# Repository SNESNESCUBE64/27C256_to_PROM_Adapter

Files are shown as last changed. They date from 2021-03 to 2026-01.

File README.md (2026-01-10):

# 27C256 to PROM Adapter

The purpose of this repo is to replace the old obselete PROMs. It is recommended that you use the Atmel AT27C256-45PU. It is a very fast OTP EPROM that can be purchased from reputable sellers such as mouser.com. All board designs are done in Kicad.

*Just as a disclaimer, these are not garunteed to work with everything. Not all of the adapters have been verified to work. As these are verified working, the table will be updated.*

## Chip Verification
| Chip | Boards Made? | Verified Working? | Test Details |
|---|---|---|---|
| 82S123 | No | No | Untested |
| 82S126 | Yes | No | Untested |
| 82S129 | Yes | Yes | Tested audio PROM 1D and Color PROM 1C on Galaga, ran for 4 hours with no issues  |
| 82S130 | Yes | No | Untested |
| 82S131 | Yes | No | Untested |
| 82S135 | No | No | Untested |
| 82S137 | No | No | Untested |
| 82S141 | No | No | Untested |
| 82S141 | No | No | Untested |
| 82S147 | No | No | Untested |
|TKG Elim| Yes | Yes | Tested working on a TRS2 Radarscope PCB set. Ran with no issues. |

## 82S123
Just a drop in replacement, no jumpers or anything. Just solder the pins, burn the rom, then solder the rom and insert in the socket!

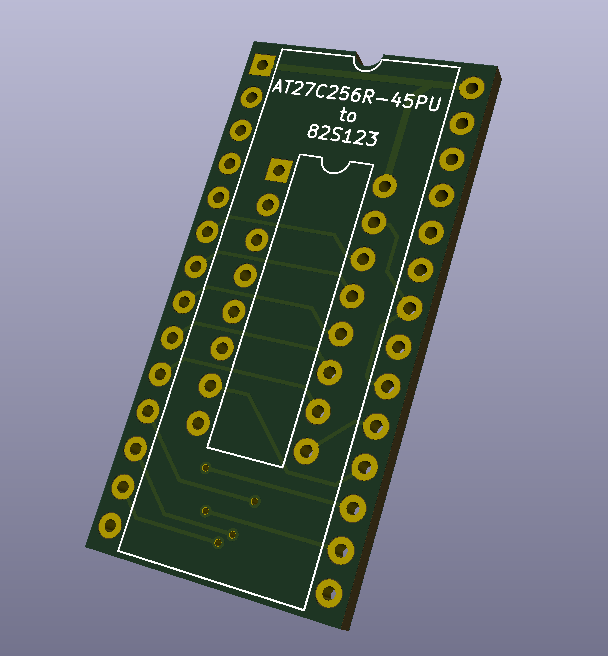
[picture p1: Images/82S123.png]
82S123


## 82S126/82S129/82S130/82S131
There are two jumpers, for 82S130/82S131, jump pins 1 and 2 for both jumper sets. For 82S126/82S129, jump pins 2 and 3 for both jumper sets. One thing to note with this, only the 4 low bits are used with this one. Make sure your binaries are not using the data in the upper bits.

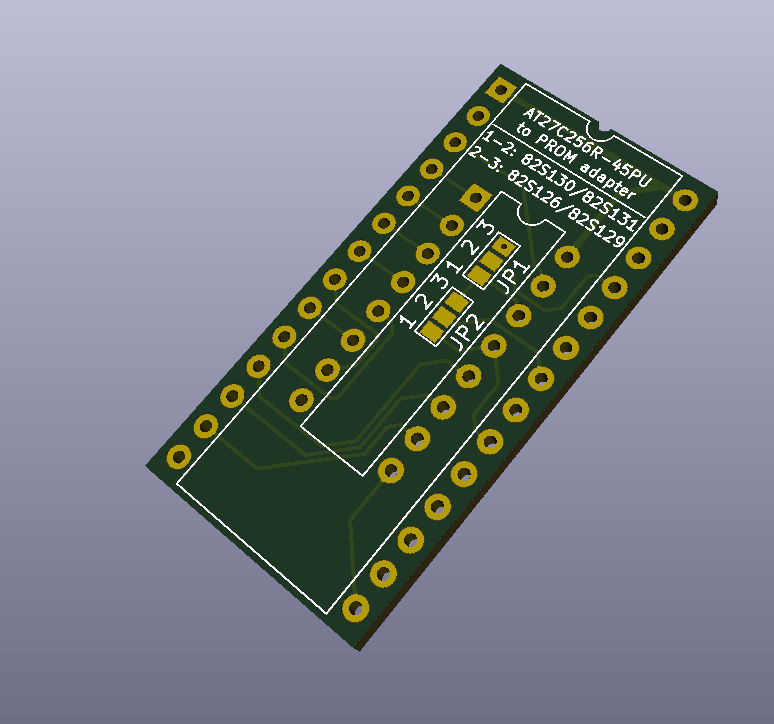
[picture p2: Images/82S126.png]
82S126/82S129/82S130/82S131


## 82S135
Just a drop in replacement, no jumpers or anything. Just solder the pins, burn the rom, then solder the rom and insert in the socket! Uses the upper 256 bytes.

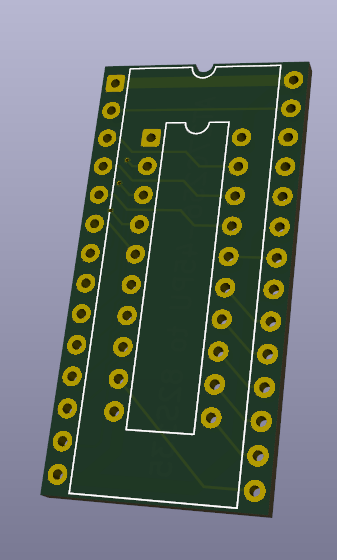
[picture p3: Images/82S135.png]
82S135


## 82S137
Just a drop in replacement, no jumpers or anything. Just solder the pins, burn the rom, then solder the rom and insert in the socket! One thing to note with this, only the 4 low bits are used with this one. Make sure your binaries are not using the data in the upper bits.

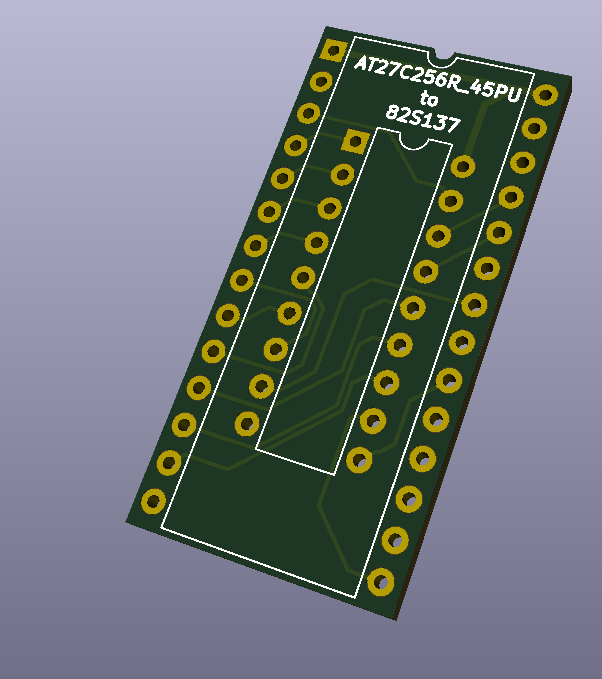
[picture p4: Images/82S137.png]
82S137


## 82S141
This one is a little bit different, it uses active circuitry to combine the chip select. It basically adds a 74ALS02 and a 0.1uF 0603 sized capacitor. The reason is because the 82S141 has four chip enables where as the 27C256 only has two. 

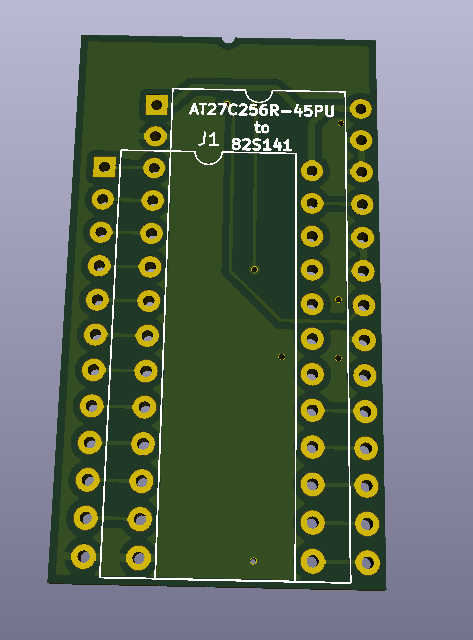
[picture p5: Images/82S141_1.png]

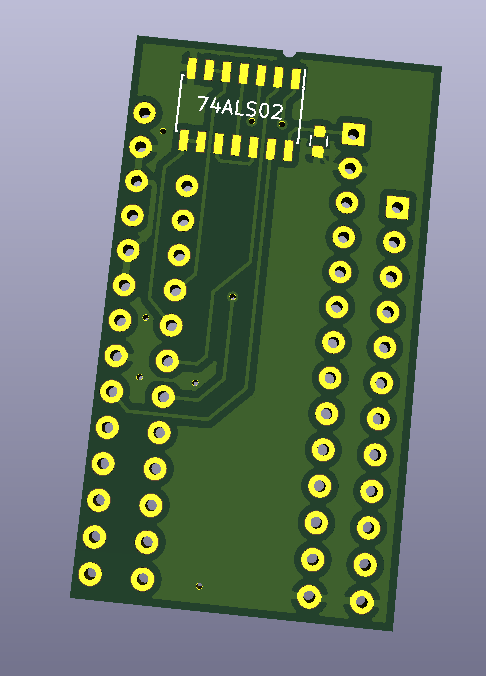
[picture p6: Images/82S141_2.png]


## TKG CPU PROM Eliminator
This is a board that combines the two PROMs found on the CPU board of Donkey Kong and Radarscope PCBs. It is more of an application than a direct PROM adapter. View the readme in the TKG CPU Eliminator folder for more details.

This has been tested and verified working on a TRS2 Radarscope PCB, but should be compatible with the following game boards:
- Radarscope (TRS2)
- Donkey Kong (TKG2)
- Donkey Kong (TKG3)
- Donkey Kong (TKG4)

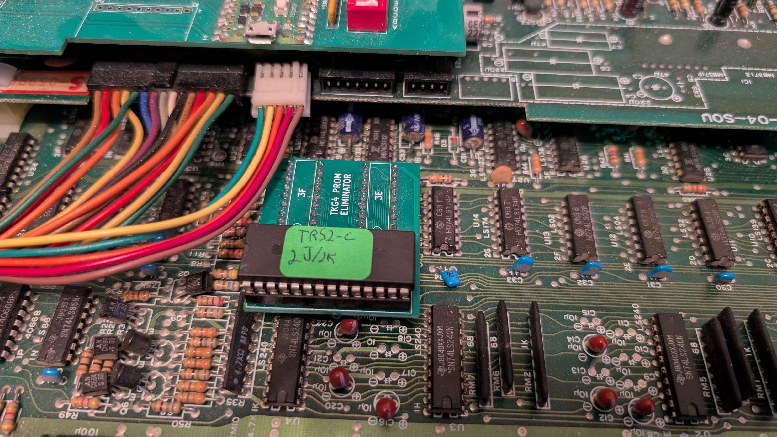
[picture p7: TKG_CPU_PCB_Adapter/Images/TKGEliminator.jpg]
TKG PROM Eliminator


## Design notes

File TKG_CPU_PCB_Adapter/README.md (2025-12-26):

# TKG PROM Eliminator
This board was designed as an alternative to the bipolar PROMs commonly found on Radarscope and Donkey Kong CPU PCBs. This combines both PROMs into one single IC to save on chips in the event that the PROMs are missing or defective. Note, this is intended to be used with **AT27C256R-45PU** high speed EPROMs. These are still available as of this time, so it makes a suitable alternative. It fits into the original two sockets without any board modifications. 

Assembled Unit

## Combining the PROM Files
Because this board relies on combining both of these PROMs into one (both are 4 bit), one has to be the upper bits and the other has to be the lower bits. 2J/3E is the lower bits, 2K/3F is the upper bits. A python script has been provided to combine the files.

Use of the python script is not required. However, I wrote it so that manual shifting of the bits and merging is unecessary. The upper PROM files have to have their byte contents shifted left by 4 and then merged together. This can be done manually but is quite tedious and prone to error. The example down shows a partial merge of the first 32 bytes.

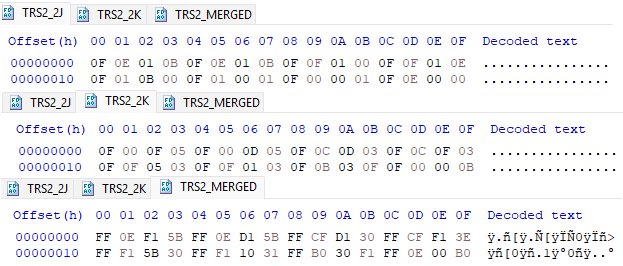
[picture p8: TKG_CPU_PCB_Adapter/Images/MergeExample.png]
Merge Exmaple


### Using the python script
The only pre-requisite is that you have to have a newer version of Python 3 installed on your computer. In order to use the python script, you will have to define the file names that you want to use in the header of the python script. You will also have to copy your PROM files into the "Scripts" folder in order to merge them.

```python
#user defined file names
promLowFilename = "TRS2_2J"
promHighFilename = "TRS2_2K"
promMergedFilename = "TRS2_MERGED"
```

promLowFilename is the file name of the 2J or 3E PROM, this is the lower bits. promHighFilename is the file name of the 2K/3F PROM, this is the upper bits. promMergedFilename is output file name.

A simple bat file is provided to easily execute it, it assumes that you have "python" as an environment variable. If you do not have that, then you will need to execute the python script another way.

### Burning the EPROM
You do not have to do anything special to burnt he eprom once you have the merged file. Duplicating to fill the EPROM is unecessary. Just load the merged PROM files at the beginning of memory for your programmer perform the programming.

## Compatibility
This has been tested and verified working on a TRS2 Radarscope PCB, but should be compatible with the following game boards:
- Radarscope (TRS2)
- Donkey Kong (TKG2)
- Donkey Kong (TKG3)
- Donkey Kong (TKG4)

It might also be compatible with Donkey Kong JR CPU PCB Boards, but I have not verified the spacing.

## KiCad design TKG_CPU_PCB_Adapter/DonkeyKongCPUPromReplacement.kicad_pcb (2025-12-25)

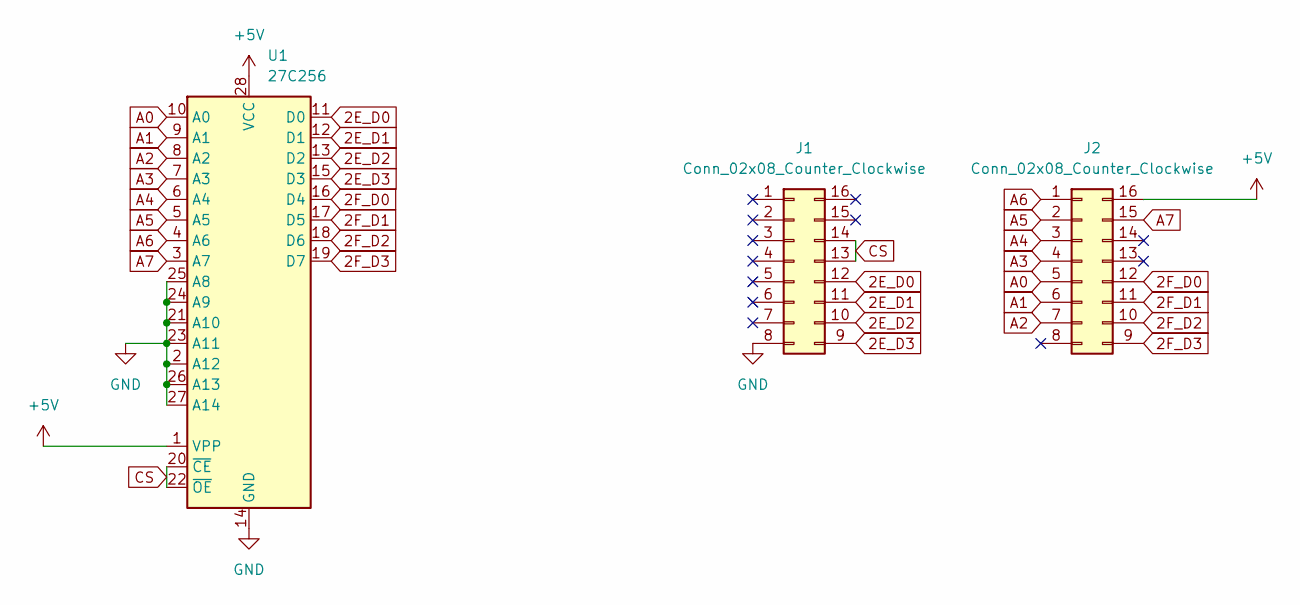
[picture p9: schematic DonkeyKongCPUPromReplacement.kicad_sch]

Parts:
J1, J2: Conn_02x08_Counter_Clockwise; DIP-16_W7.62mm
U1: 27C256; DIP-28_W15.24mm_Socket

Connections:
2E_D0: J1.12, U1.11 (D0)
2E_D1: J1.11, U1.12 (D1)
2E_D2: J1.10, U1.13 (D2)
2E_D3: J1.9, U1.15 (D3)
2F_D0: J2.12, U1.16 (D4)
2F_D1: J2.11, U1.17 (D5)
2F_D2: J2.10, U1.18 (D6)
2F_D3: J2.9, U1.19 (D7)
+5V: J2.16, U1.1 (VPP), U1.28 (VCC)
A0: J2.5, U1.10 (A0)
A1: J2.6, U1.9 (A1)
A2: J2.7, U1.8 (A2)
A3: J2.4, U1.7 (A3)
A4: J2.3, U1.6 (A4)
A5: J2.2, U1.5 (A5)
A6: J2.1, U1.4 (A6)
A7: J2.15, U1.3 (A7)
CS: J1.13, J1.14, U1.20 (~CE), U1.22 (~OE)
GND: J1.8, U1.2 (A12), U1.14 (GND), U1.21 (A10), U1.23 (A11), U1.24 (A9), U1.25 (A8), U1.26 (A13), U1.27 (A14)

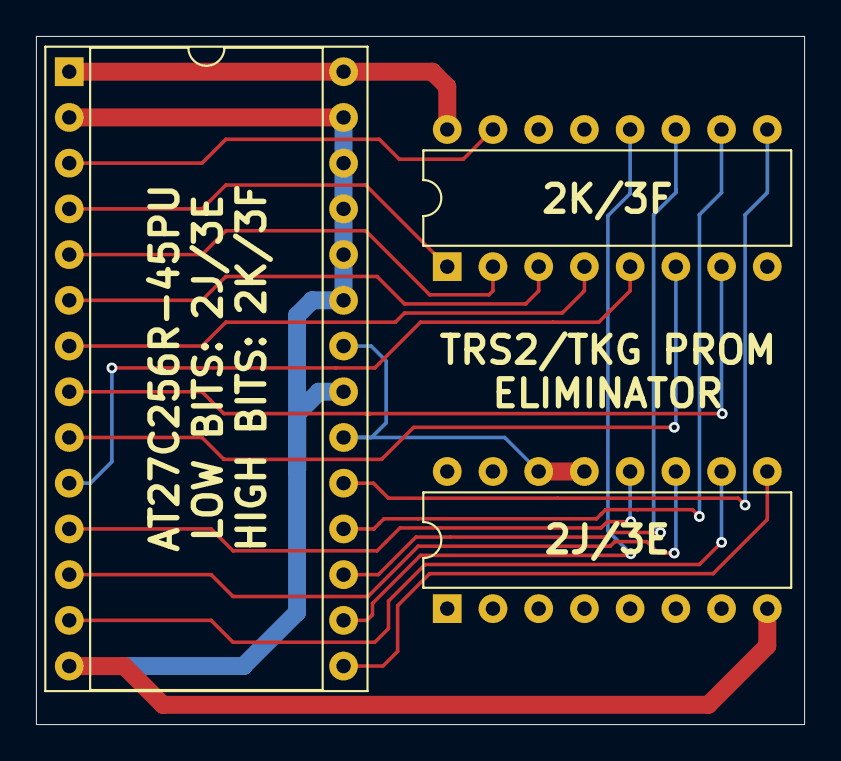
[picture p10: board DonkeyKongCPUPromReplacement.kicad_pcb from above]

Board: 2 copper layers, 42.7 x 38.2 mm, 3 parts (0 on the bottom side), 19 nets.

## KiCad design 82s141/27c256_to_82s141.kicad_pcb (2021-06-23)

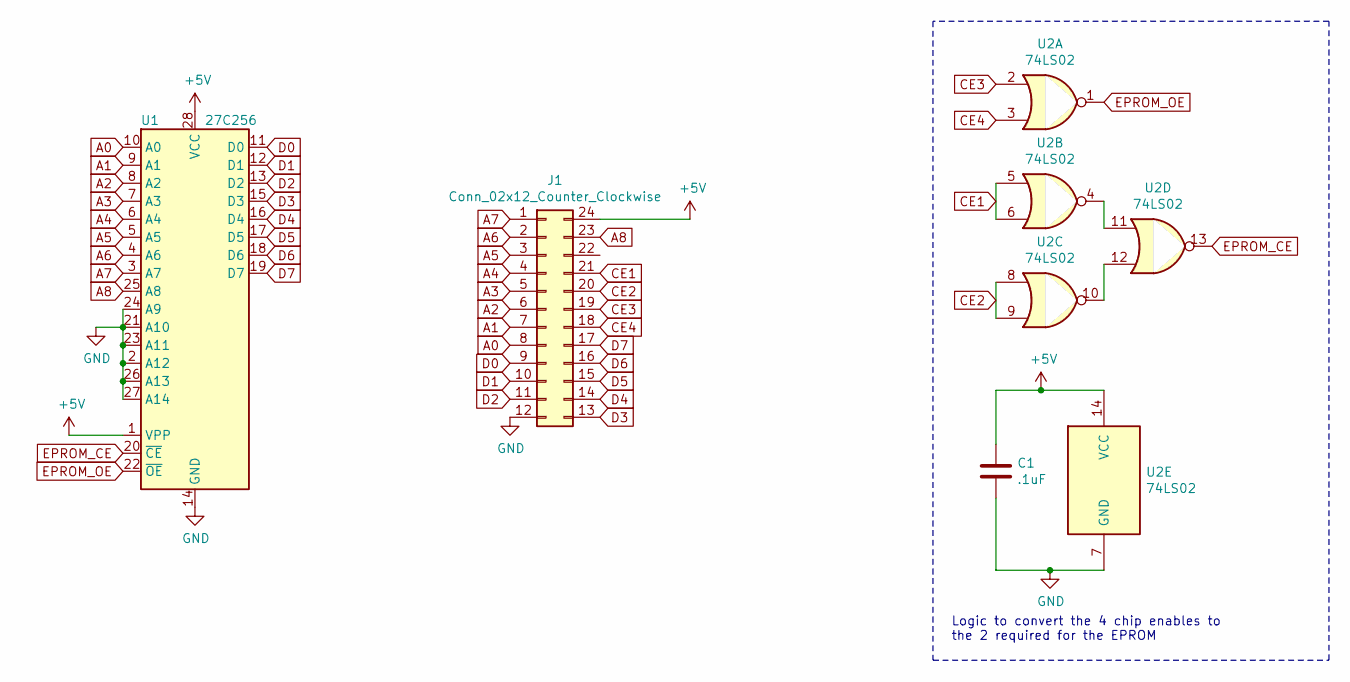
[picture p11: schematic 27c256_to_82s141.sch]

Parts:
C1: .1uF; C_0603
J1: Conn_02x12_Counter_Clockwise; DIP-24_W7.62mm
U1: 27C256; DIP-28_W15.24mm
U2: 74LS02; SOIC-14_3.9x8.7mm_Pitch1.27mm

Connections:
+5V: C1.1, J1.24, U1.1 (VPP), U1.28 (VCC), U2.14 (VCC)
A0: J1.8, U1.10 (A0)
A1: J1.7, U1.9 (A1)
A2: J1.6, U1.8 (A2)
A3: J1.5, U1.7 (A3)
A4: J1.4, U1.6 (A4)
A5: J1.3, U1.5 (A5)
A6: J1.2, U1.4 (A6)
A7: J1.1, U1.3 (A7)
A8: J1.23, U1.25 (A8)
CE1: J1.21, U2.5, U2.6
CE2: J1.20, U2.8, U2.9
CE3: J1.19, U2.2
CE4: J1.18, U2.3
D0: J1.9, U1.11 (D0)
D1: J1.10, U1.12 (D1)
D2: J1.11, U1.13 (D2)
D3: J1.13, U1.15 (D3)
D4: J1.14, U1.16 (D4)
D5: J1.15, U1.17 (D5)
D6: J1.16, U1.18 (D6)
D7: J1.17, U1.19 (D7)
EPROM_CE: U1.20 (~CE), U2.13
EPROM_OE: U1.22 (~OE), U2.1
GND: C1.2, J1.12, U1.2 (A12), U1.14 (GND), U1.21 (A10), U1.23 (A11), U1.24 (A9), U1.26 (A13), U1.27 (A14), U2.7 (GND)
unnamed: U2.10, U2.12
unnamed: U2.4, U2.11

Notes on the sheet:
Logic to convert the 4 chip enables to the 2 required for the EPROM

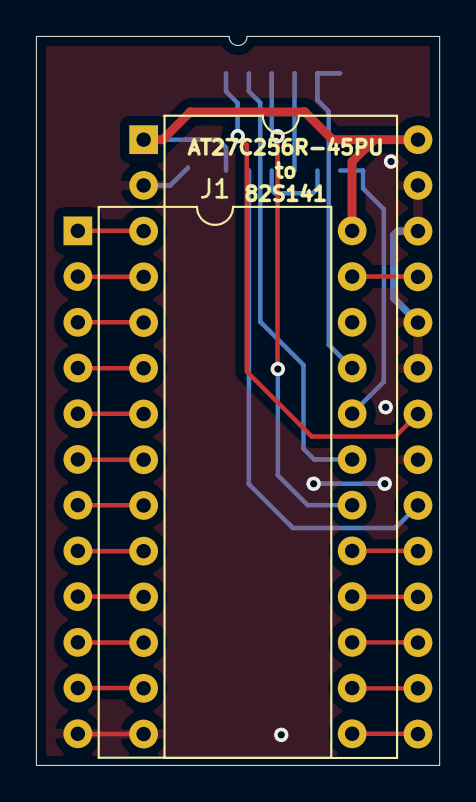
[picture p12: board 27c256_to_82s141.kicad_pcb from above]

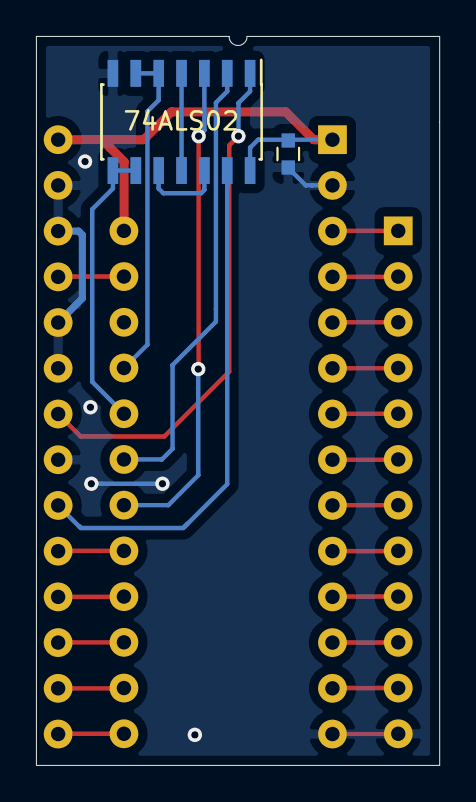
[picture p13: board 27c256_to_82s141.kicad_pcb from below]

Board: 2 copper layers, 22.4 x 40.5 mm, 4 parts (2 on the bottom side), 27 nets.

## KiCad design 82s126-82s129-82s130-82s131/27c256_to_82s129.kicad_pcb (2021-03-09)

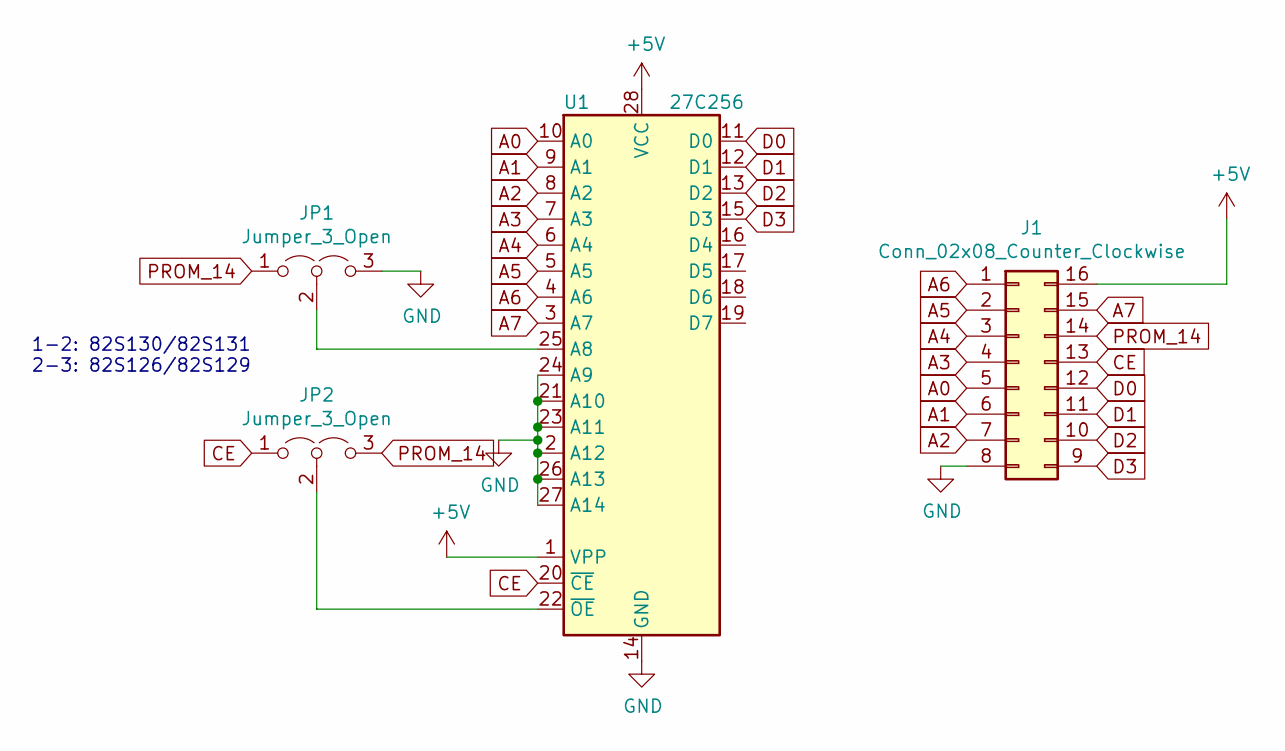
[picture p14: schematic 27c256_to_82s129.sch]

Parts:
J1: Conn_02x08_Counter_Clockwise; DIP-16_W7.62mm
JP1, JP2: Jumper_3_Open; GS3
U1: 27C256; DIP-28_W15.24mm

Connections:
+5V: J1.16, U1.1 (VPP), U1.28 (VCC)
A0: J1.5, U1.10 (A0)
A1: J1.6, U1.9 (A1)
A2: J1.7, U1.8 (A2)
A3: J1.4, U1.7 (A3)
A4: J1.3, U1.6 (A4)
A5: J1.2, U1.5 (A5)
A6: J1.1, U1.4 (A6)
A7: J1.15, U1.3 (A7)
CE: J1.13, JP2.1 (A), U1.20 (~CE)
D0: J1.12, U1.11 (D0)
D1: J1.11, U1.12 (D1)
D2: J1.10, U1.13 (D2)
D3: J1.9, U1.15 (D3)
GND: J1.8, JP1.3 (B), U1.2 (A12), U1.14 (GND), U1.21 (A10), U1.23 (A11), U1.24 (A9), U1.26 (A13), U1.27 (A14)
unnamed: JP1.2 (C), U1.25 (A8)
unnamed: JP2.2 (C), U1.22 (~OE)
PROM_14: J1.14, JP1.1 (A), JP2.3 (B)

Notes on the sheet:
1-2: 82S130/82S131 2-3: 82S126/82S129

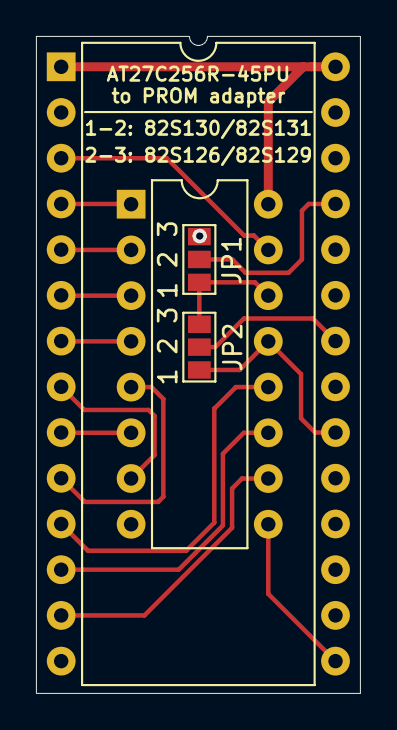
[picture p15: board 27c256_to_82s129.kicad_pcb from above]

Board: 2 copper layers, 18.0 x 36.5 mm, 4 parts (0 on the bottom side), 18 nets.

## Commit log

2021-03-09 added 82s126 adapter
    [27c256_to_82s129-B_Cu.gbr, 27c256_to_82s129-B_Mask.gbr, 27c256_to_82s129-B_Paste.gbr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]
2021-03-20 Added a 82S123 adapter
    [27c256_to_82s123-B_Cu.gbr, 27c256_to_82s123-B_Mask.gbr, 27c256_to_82s123-B_Paste.gbr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]
2021-03-20 Changed the silkscreen on the PCB to be more specific
    [27c256_to_82s123-B_Cu.gbr, 27c256_to_82s123-B_Mask.gbr, 27c256_to_82s123-B_Paste.gbr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]
2021-03-21 Added 82S137
    [27C256_to_82s137-B_Cu.gbr, 27C256_to_82s137-B_Mask.gbr, 27C256_to_82s137-B_Paste.gbr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]
2021-03-21 Added 84S141 Adapters
    [27c256_to_82s141-B_Cu.gbr, 27c256_to_82s141-B_Mask.gbr, 27c256_to_82s141-B_Paste.gbr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]
2021-06-23 Added 82S147 and redid 82S141
    [27c256_to_82s141-B_Cu.gbr, 27c256_to_82s141-B_Mask.gbr, 27c256_to_82s141-B_Paste.gbr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]
2025-12-25 Added TKG CPU PROM Eliminator
    [DonkeyKongCPUPromReplacement-B_Cu.gbr, DonkeyKongCPUPromReplacement-B_Mask.gbr, DonkeyKongCPUPromReplacement-B_Paste.gbr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]
2026-01-10 Added 82S135 Adapter
    [27c256_to_82s135-B_Cu.gbr, 27c256_to_82s135-B_Mask.gbr, 27c256_to_82s135-B_Paste.gbr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]
